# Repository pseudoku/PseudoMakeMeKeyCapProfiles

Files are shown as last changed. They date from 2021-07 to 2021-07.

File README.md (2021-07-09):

# Pseudo Make Me Key Cap Profile

## How to
* make sure OpenSCAD is up to date.
* unzip libraries.zip into your OpenSCAD libraries
* select keycap you want to render by changing KeyID value
* change KeyID to corresponding Parameter ID
* press F5 to review
* press F6 to render
* press F7 to export as STL

#Some notes on
## Distorted Ellipsoidal Saddle (DES)
High sculpt smooth transition profile
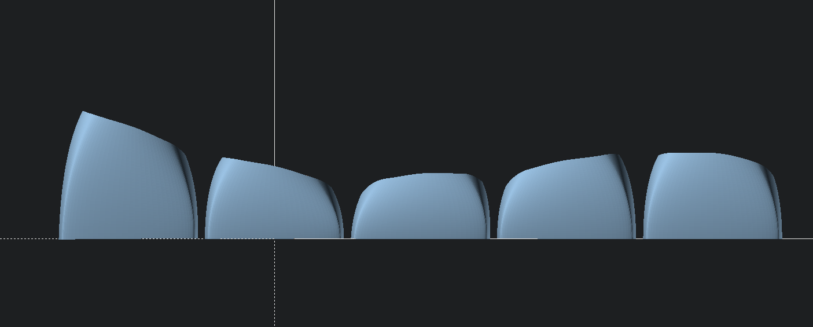
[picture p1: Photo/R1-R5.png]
DES

### Standard
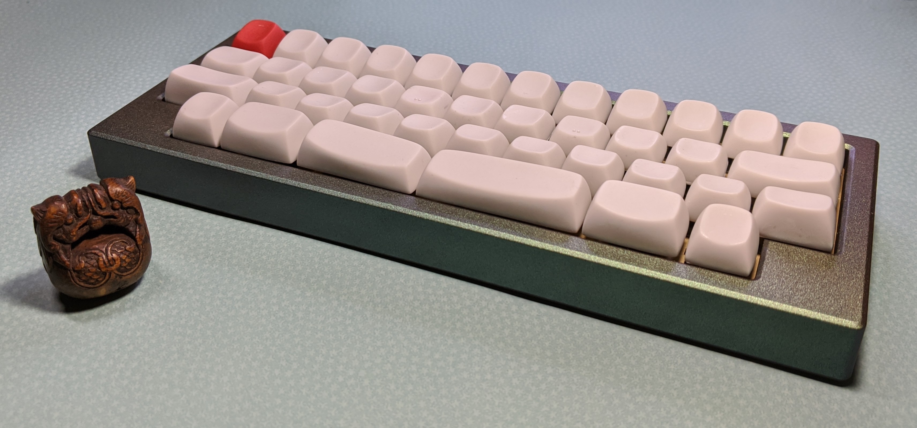
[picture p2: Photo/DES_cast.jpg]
Neuron v1


### Concave
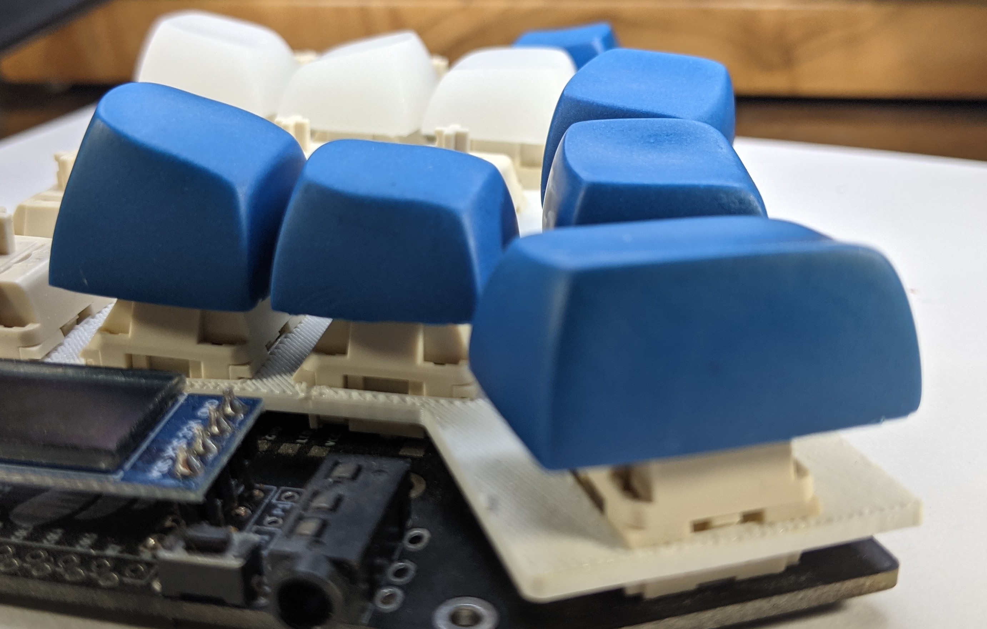
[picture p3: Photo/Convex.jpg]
Corne thumb and Convex Caps


### Thumbs
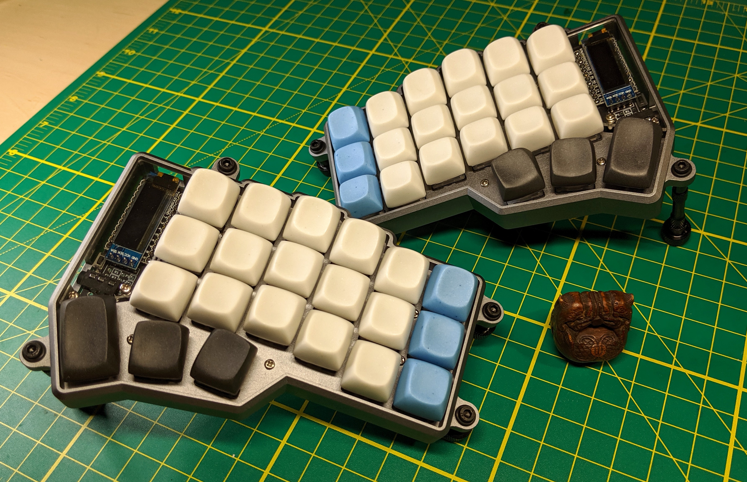
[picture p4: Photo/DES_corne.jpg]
IMK Corne v1

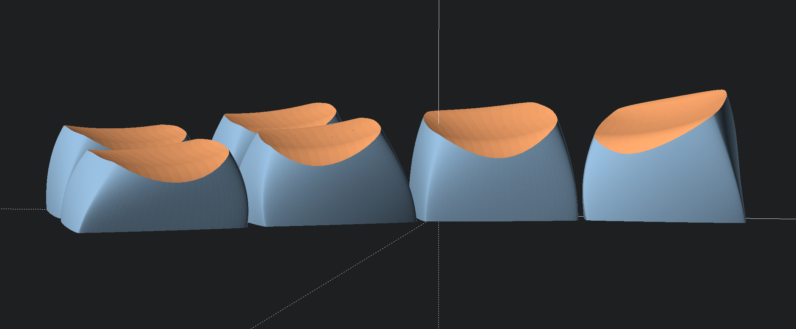
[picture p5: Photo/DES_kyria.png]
Kyria


### Chicago Stenographer
Subtly sculpted choc spaced low profile
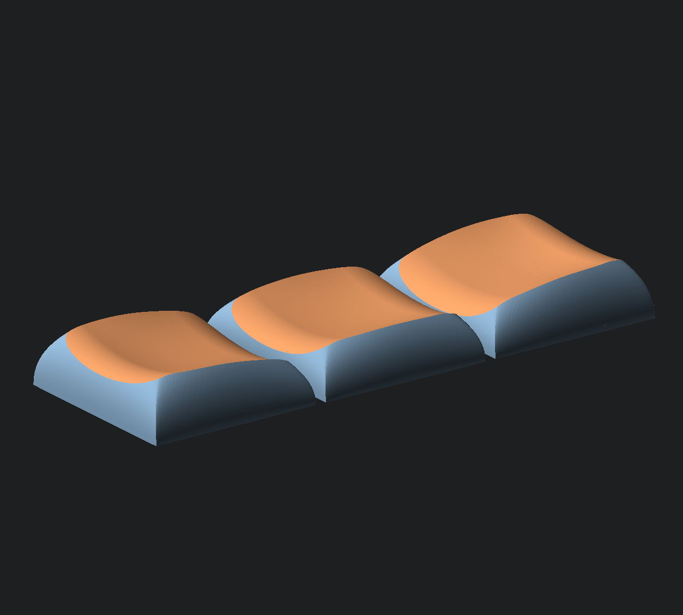
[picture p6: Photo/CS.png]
CS

#### Standard
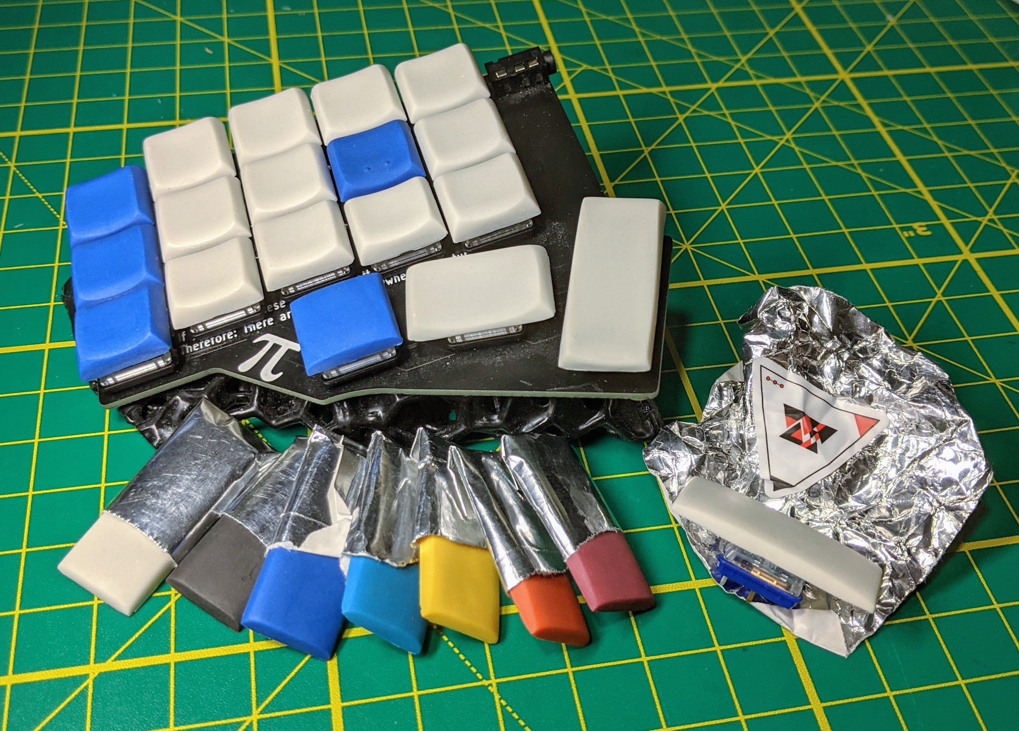
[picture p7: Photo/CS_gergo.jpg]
Look


#### Convex
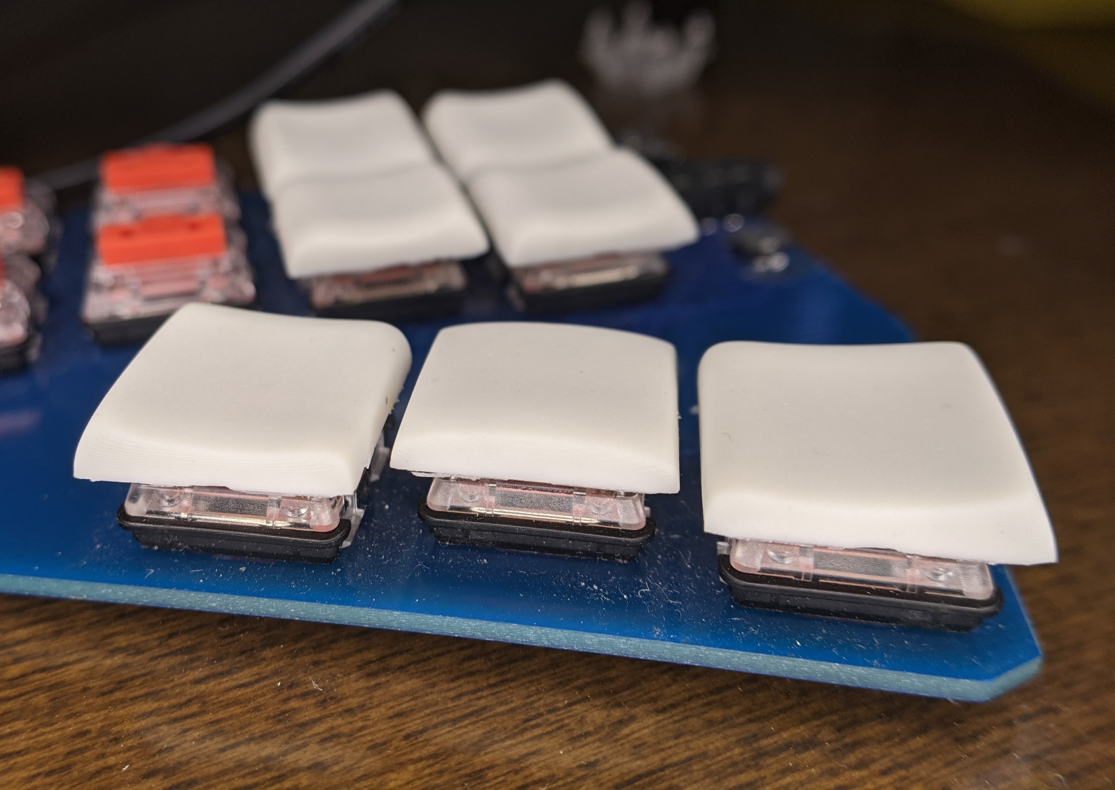
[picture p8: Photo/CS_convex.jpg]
Georgi

#### Thumbs
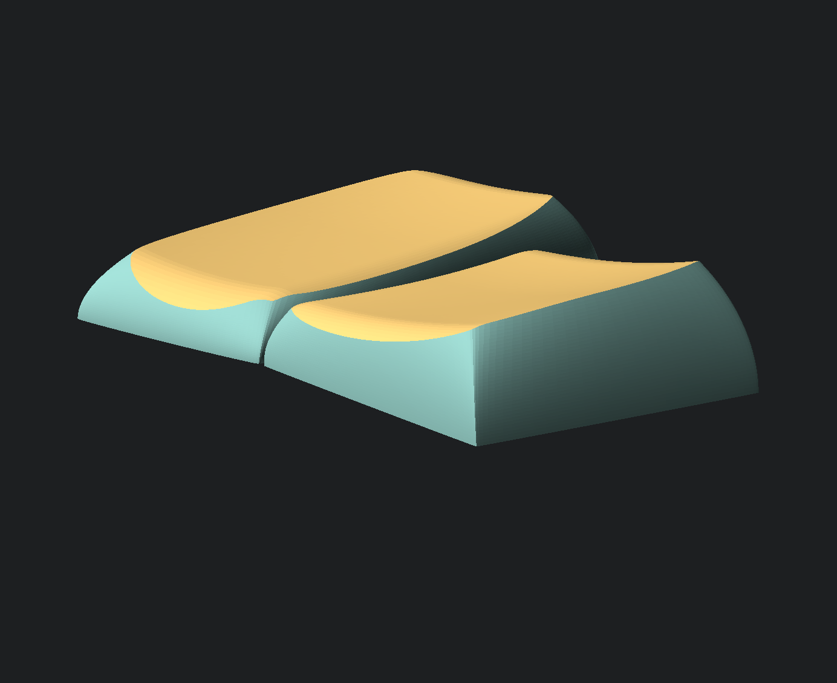
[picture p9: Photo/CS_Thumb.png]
1.5 + 1

Additional sculpt angle and smoother transitions

### Philadelphia Minimalist
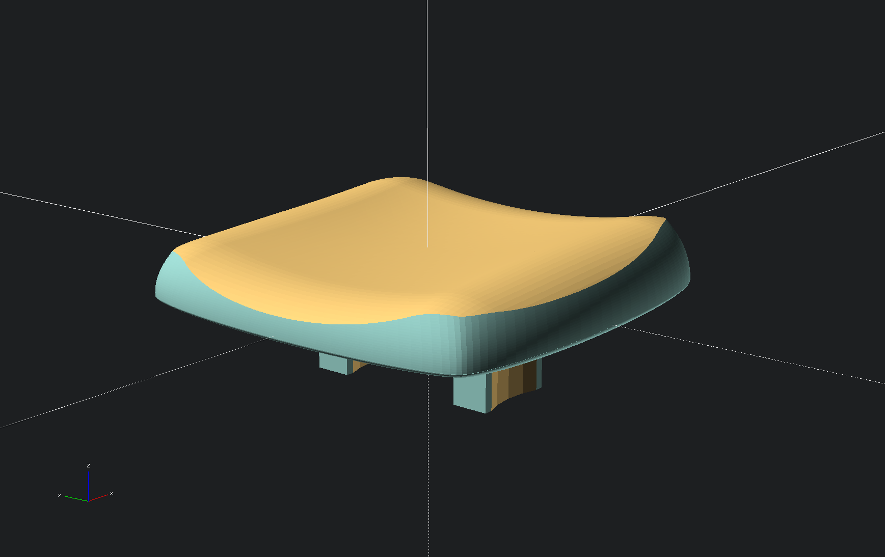
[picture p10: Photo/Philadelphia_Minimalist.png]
under

Minimal spacing
Under construction

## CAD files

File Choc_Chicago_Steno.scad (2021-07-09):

use <scad-utils/morphology.scad> //for cheaper minwoski 
use <scad-utils/transformations.scad>
use <scad-utils/shapes.scad>
use <scad-utils/trajectory.scad>
use <scad-utils/trajectory_path.scad>
use <sweep.scad>
use <skin.scad> 
//use <z-butt.scad> 

//Choc Chord version Chicago Stenographer

/*Tester */
keycap(
  keyID  = 1, //change profile refer to KeyParameters Struct
  cutLen = 0, //Don't change. for chopped caps
  Stem   = true, //tusn on shell and stems
  StemRot = 0, //change stem orientation by deg
  Dish   = true, //turn on dish cut
  Stab   = 0, 
  visualizeDish = false, // turn on debug visual of Dish 
  crossSection  = false, // center cut to check internal
  homeDot = false, //turn on homedots
  Legends = false
  ); 

//-Parameters
wallthickness = 1.1; // 1.75 for mx size, 1.1
topthickness = 2.5; //2 for phat 3 for chicago
stepsize = 50;  //resolution of Trajectory
step = 2;       //resolution of ellipes 
fn = 32;          //resolution of Rounded Rectangles: 60 for output
layers = 40;    //resolution of vertical Sweep: 50 for output

//---Stem param
slop    = 0.3;
stemRot = 0;
stemWid = 8;
stemLen = 6;
stemCrossHeight = 1.8;
extra_vertical = 0.6;
stemLayers = 50; //resolution of stem to cap top transition
//#cube([18.16, 18.16, 10], center = true); // sanity check border

//injection param
draftAngle = 0; //degree  note:Stem Only
//TODO: Add wall thickness transition?


keyParameters = //keyParameters[KeyID][ParameterID]
[
//  BotWid, BotLen, TWDif, TLDif, keyh, WSft, LSft  XSkew, YSkew, ZSkew, WEx, LEx, CapR0i, CapR0f, CapR1i, CapR1f, CapREx, StemEx
    //Column 0    
    //Levee: Chicago in choc Dimension 
    [17.20,  16.00,   5.6, 	   5,  4.9,    0,   .0,     5,    -0,    -0,   2, 2.5,    .10,      2,     .10,      3,     2,       2], //Chicago Steno R2/R4
    [17.20,  16.00,   5.6, 	   5,  4.5,    0,   .0,     0,    -0,    -0,   2, 2.5,    .10,      3,     .10,      3,     2,       2], //Chicago Steno R3 flat
    [17.20,  16.00,  1.25, 	1.25,  4.5,    0,   .0,     0,    -0,    -0,   2, 2.5,    .10,     .5,     .10,     .5,     2,       2], //Chicago Steno R3 chord
    //mods 3
    
    [17.20,  16.00,  4.25, 	3.25,  5.5,  -.7,  0.7,     0,    -4,    -0,   2,   2,    .10,      2,     .10,      2,     2,       2], //Levee Corner R2
    [17.20,  16.00,  4.25, 	3.25,  5.2,  -.8,  0.6,     0,    -4,    -0,   2,   3,    .10,      2,     .10,      2,     2,       2], //Levee Corner R2
    //1.25 5
    [21.3,   15.60,  5.6, 	   5,  4.5,    0,   .0,     5,    -0,    -0,   2,   2,     .5,      3,      .5,      3,     2,       2], //Chicago Steno R2/R4 1.25u
    [21.4,   15.60,  5.6, 	   5,  4.5,    0,   .0,     0,    -0,    -0,   2,   2,     .5,      3,      .5,      3,     2,       2], //Chicago Steno R3 1.25u
    //1.5 7
    [26.15,  15.60,   5.6, 	   5,  4.5,    0,   .0,     5,    -0,    -0,   2,   2,     .5,      3,      .5,      3,     2,       2], //Chicago Steno R2/R4 1.5
    [26.15,  15.60,   5.6, 	   5,  4.5,    0,   .0,     0,    -0,    -0,   2,   2,     .5,      3,      .5,      3,     2,       2], //Chicago Steno R3 1.5u
    //1.75 9
    [30.90,  15.60,   5.6, 	   5,  4.5,    0,   .0,     5,    -0,    -0,   2,   2,     .5,      3,      .5,      3,     2,       2], //Chicago Steno R2/R4 1.5
    [30.90,  15.60,   5.6, 	   5,  4.5,    0,   .0,     0,    -0,    -0,   2,   2,     .5,      3,      .5,      3,     2,       2], //Chicago Steno R3 1.5u
    //2.00 11
    [35.70,  15.60,   5.6, 	   5,  4.5,    0,   .0,     5,    -0,    -0,   2,   2,     .5,      3,      .5,      3,     2,       2], //Chicago Steno R2/R4 1.5
    [30.90,  15.60,   5.6, 	   5,  4.5,    0,   .0,     0,    -0,    -0,   2,   2,     .5,      3,      .5,      3,     2,       2], //Chicago Steno R3 1.5u
    // Ergo shits
    [18.75,  18.75,   5.6, 	   5,    8,    0,   .25,     0,    -0,    -0,   2, 2.5,    .10,      3,     .10,      3,     2,       2], //highpro 19.05 R2|4 
    [17.20,  16.00,   5.6, 	   5,  4.7,    0,   .0,      3,    -0,    -0,   2, 2.5,    .10,      2,     .10,      3,     2,       2], //Chicago Steno R2 ALT
    [17.20,  16.00,   5.6, 	   5,  5.5,    0,   .0,      7,    -0,    -0,   2, 2.5,    .10,      2,     .10,      3,     2,       2], //Chicago Steno R1 Steap
    [17.20,  16.00,   5.6, 	   5,  7.0,    0,   .0,     10,    -0,    -0,   2, 2.5,    .10,      2,     .10,      3,     2,       2] //Chicago Steno R1 mild with alt R2
];

dishParameters = //dishParameter[keyID][ParameterID]
[ 
//FFwd1 FFwd2 FPit1 FPit2  DshDep DshHDif FArcIn FArcFn FArcEx     BFwd1 BFwd2 BPit1 BPit2  BArcIn BArcFn BArcEx
  //Column 0
  [ 4.5,    4,    7,  -50,      7,    1.7,   11,    17,     2,      4.5,    4,    2,   -35,   11,    15,     2], //Chicago Steno R2/R4
  [ 4.5,    4,    5,  -40,      7,    1.7,   11,    15,     2,      4.5,    4,    5,   -40,   11,    15,     2], //Chicago Steno R3 flat
  [ 4.5,    4,    5,  -40,      7,    1.7,   11,    15,     2,      4.5,    4,    5,   -40,   11,    15,     2], //Chicago Steno R3 chord
  
  [   6,  3.5,    7,  -50,      5,    1.0,   16,    23,     2,        6,  3.5,    7,   -50,   16,    23,     2], //Levee Steno R2/R4
  [   6,  3.5,    7,  -50,      5,    1.0,   16,    23,     2,        6,  3.5,    7,   -50,   16,    23,     2], //Levee Steno R2/R4
  //1.25
  [ 4.5,    4,    7,  -40,      8,    1.8,   15,    20,     2,      4.5,    4,    2,   -35,   15,    20,     2], //Chicago Steno R2/R4
  [ 4.5,    4,    5,  -40,      8,    1.8,   15,    20,     2,      4.5,    4,    5,   -40,   15,    20,     2], //Chicago Steno R3
  //1.5
  [ 4.5,    4,    7,  -40,      8,    1.8,   19,    25,     2,      4.5,    4,    2,   -35,   19,    25,     2], //Chicago Steno R2/R4
  [ 4.5,    4,    5,  -40,      8,    1.8,   19,    25,     2,      4.5,    4,    5,   -40,   19,    25,     2], //Chicago Steno R3
  //1.75
  [ 4.5,    4,    7,  -40,      8,    1.8,   22.5,  27,     2,      4.5,    4,    2,   -35,   22.5,  27,     2], //Chicago Steno R2/R4
  [ 4.5,    4,    5,  -40,      8,    1.8,   22.5,  27,     2,      4.5,    4,    5,   -40,   22.5,  27,     2], //Chicago Steno R3
  //2.00
  [ 4.5,    4,    7,  -40,      8,    1.8,   22.5,  27,     2,      4.5,    4,    2,   -35,   22.5,  27,     2], //Chicago Steno R2/R4
  [ 4.5,    4,    5,  -40,      8,    1.8,   22.5,  27,     2,      4.5,    4,    5,   -40,   22.5,  27,     2], //Chicago Steno R3
  
  [   5,    5,    5,  -40,      7,    1.7,   11,    15,     2,        5,    5,    5,   -40,   11,    15,     2], //Chicago Steno R3 flat
  [ 4.5,    4,    7,  -50,      7,    1.7,   11,    17,     2,      4.5,    4,    2,   -35,   11,    15,     2], //Chicago Steno R1
  [ 4.5,    4,    7,  -50,      7,    1.7,   11,    17,     2,      4.5,    4,    2,   -35,   11,    15,     2], //Chicago Steno R1
  [ 4.5,    4,    7,  -50,      7,    1.7,   11,    17,     2,      4.5,    4,    2,   -35,   11,    15,     2] //Chicago Steno R1
];


function BottomWidth(keyID)  = keyParameters[keyID][0];  //
function BottomLength(keyID) = keyParameters[keyID][1];  // 
function TopWidthDiff(keyID) = keyParameters[keyID][2];  //
function TopLenDiff(keyID)   = keyParameters[keyID][3];  //
function KeyHeight(keyID)    = keyParameters[keyID][4];  //
function TopWidShift(keyID)  = keyParameters[keyID][5];
function TopLenShift(keyID)  = keyParameters[keyID][6];
function XAngleSkew(keyID)   = keyParameters[keyID][7];
function YAngleSkew(keyID)   = keyParameters[keyID][8];
function ZAngleSkew(keyID)   = keyParameters[keyID][9];
function WidExponent(keyID)  = keyParameters[keyID][10];
function LenExponent(keyID)  = keyParameters[keyID][11];
function CapRound0i(keyID)   = keyParameters[keyID][12];
function CapRound0f(keyID)   = keyParameters[keyID][13];
function CapRound1i(keyID)   = keyParameters[keyID][14];
function CapRound1f(keyID)   = keyParameters[keyID][15];
function ChamExponent(keyID) = keyParameters[keyID][16];
function StemExponent(keyID) = keyParameters[keyID][17];

function FrontForward1(keyID) = dishParameters[keyID][0];  //
function FrontForward2(keyID) = dishParameters[keyID][1];  // 
function FrontPitch1(keyID)   = dishParameters[keyID][2];  //
function FrontPitch2(keyID)   = dishParameters[keyID][3];  //
function DishDepth(keyID)     = dishParameters[keyID][4];  //
function DishHeightDif(keyID) = dishParameters[keyID][5];  //
function FrontInitArc(keyID)  = dishParameters[keyID][6];
function FrontFinArc(keyID)   = dishParameters[keyID][7];
function FrontArcExpo(keyID)  = dishParameters[keyID][8];
function BackForward1(keyID)  = dishParameters[keyID][9];  //
function BackForward2(keyID)  = dishParameters[keyID][10];  // 
function BackPitch1(keyID)    = dishParameters[keyID][11];  //
function BackPitch2(keyID)    = dishParameters[keyID][12];  //
function BackInitArc(keyID)   = dishParameters[keyID][13];
function BackFinArc(keyID)    = dishParameters[keyID][14];
function BackArcExpo(keyID)   = dishParameters[keyID][15];
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

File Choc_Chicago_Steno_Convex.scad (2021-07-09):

use <scad-utils/morphology.scad> //for cheaper minwoski 
use <scad-utils/transformations.scad>
use <scad-utils/shapes.scad>
use <scad-utils/trajectory.scad>
use <scad-utils/trajectory_path.scad>
use <sweep.scad>
use <skin.scad>  
//use <z-butt.scad>

//NOTE: with sweep cuts, top surface may not be visible in review, it should be visible once rendered

mirror([0,0,0])keycap(
  keyID  = 1, //change profile refer to KeyParameters Struct
  cutLen = 0, //Don't change. for chopped caps
  Stem   = true, //tusn on shell and stems
  StemRot = 0,//change stem orientation by deg
  Dish   = true, //turn on dish cut
  Stab   = 0, 
  visualizeDish = false, // turn on debug visual of Dish 
  crossSection  = false, // center cut to check internal
  homeDot = false, //turn on homedots
  Legends = false
); 

//Parameters
wallthickness = 1.2;   
topthickness  = 2;   //
stepsize      = 50;  //resolution of Trajectory
step          = 1;   //resolution of ellipes 
fn            = 32;  //resolution of Rounded Rectangles: 60 for output
layers        = 40;  //resolution of vertical Sweep: 50 for output
dotRadius     = 1.25;   //home dot size
//---Stem param
slop    = 0.25;
stemWid = 8;
stemLen = 6;
stemCrossHeight = 1.8;
extra_vertical  = 0.6;
StemBrimDep     = 0; 
stemLayers      = 50; //resolution of stem to cap top transition
driftAngle      = 0;

keyParameters = //keyParameters[KeyID][ParameterID]
[
//  BotWid, BotLen, TWDif, TLDif, keyh, WSft, LSft  XSkew, YSkew, ZSkew, WEx, LEx, CapR0i, CapR0f, CapR1i, CapR1f, CapREx, StemEx
    //Column 0    
    //Levee: Chicago in choc Dimension 
    [17.20,  16.00,   5.6, 	   5,  3.8,    0,  -.5,     7,    -0,    -0,   2, 2,    .10,      3,     .10,      3,     2,       2], //Chicago Steno R2x 1u
    [17.20,  16.00,   5.6, 	   5,  4.4,    0,   .0,     0,    -0,    -0,   2, 2,    .10,      3,     .10,      3,     2,       2], //Chicago Steno R3x 1u
    [35.85,  15.65,     7, 	   7,  4.4,    0,   .0,     0,    -0,    -0,   2, 2,    .30,      5,     .30,      5,     2,       2], //Chicago Steno R3x 1.5u 
    [35.85,  15.65,     7, 	   7,  4.4,    0,   .0,     0,    -0,    -0,   2, 2,    .30,      5,     .30,      5,     2,       2], //Chicago Steno R3x 2u 
    //mods 3
    
    [17.20,  16.00,  4.25, 	3.25,  5.5,  -.7,  0.7,     0,    -4,    -0,   2,   2,    .10,      2,     .10,      2,     2,       2], //Levee Corner R2
    [17.20,  16.00,  4.25, 	3.25,  5.2,  -.8,  0.6,     0,    -4,    -0,   2,   3,    .10,      2,     .10,      2,     2,       2], //Levee Corner R2
    //1.25 5
    [21.3,   15.60,  5.6, 	   5,  4.5,    0,   .0,     5,    -0,    -0,   2,   2,     .5,      3,      .5,      3,     2,       2], //Chicago Steno R2/R4 1.25u
    [21.4,   15.60,  5.6, 	   5,  4.5,    0,   .0,     0,    -0,    -0,   2,   2,     .5,      3,      .5,      3,     2,       2], //Chicago Steno R3 1.25u
    //1.5 7
    [26.15,  15.60,   5.6, 	   5,  4.5,    0,   .0,     5,    -0,    -0,   2,   2,     .5,      3,      .5,      3,     2,       2], //Chicago Steno R2/R4 1.5
    [26.15,  15.60,   5.6, 	   5,  4.5,    0,   .0,     0,    -0,    -0,   2,   2,     .5,      3,      .5,      3,     2,       2], //Chicago Steno R3 1.5u
    //1.75 9
    [30.90,  15.60,   5.6, 	   5,  4.5,    0,   .0,     5,    -0,    -0,   2,   2,     .5,      3,      .5,      3,     2,       2], //Chicago Steno R2/R4 1.5
    [30.90,  15.60,   5.6, 	   5,  4.5,    0,   .0,     0,    -0,    -0,   2,   2,     .5,      3,      .5,      3,     2,       2], //Chicago Steno R3 1.5u
    // Ergo shits
    [18.75,  18.75,   5.6, 	   5,    8,    0,   .25,     0,    -0,    -0,   2, 2.5,    .10,      3,     .10,      3,     2,       2], //highpro 19.05 R2|4 
    [17.20,  16.00,   5.6, 	   5,  4.7,    0,   .0,      3,    -0,    -0,   2, 2.5,    .10,      2,     .10,      3,     2,       2], //Chicago Steno R2 ALT
    [17.20,  16.00,   5.6, 	   5,  5.5,    0,   .0,      7,    -0,    -0,   2, 2.5,    .10,      2,     .10,      3,     2,       2], //Chicago Steno R1 Steap
    [17.20,  16.00,   5.6, 	   5,  7.0,    0,   .0,     10,    -0,    -0,   2, 2.5,    .10,      2,     .10,      3,     2,       2], //Chicago Steno R1 mild with alt R2
];

dishParameters = //dishParameter[keyID][ParameterID]
[ 
//FFwd1 FFwd2 FPit1 FPit2  DshDepi DishDepf,DshHDif FArcIn FArcFn FArcEx     BFwd1 BFwd2 BPit1 BPit2  BArcIn BArcFn BArcEx
  [   5,  2.3,    2,  -55,    1.5,   3.75,   8.5,    8.5,    2,       5,    3,    2,  -50,    8.5,    8.7 ,     2], //R2x 1u
  [ 4.5,  3.3,   -3,  -45,    1.5,   3.75,   8.5,   8.7,     2,     4.5,  3.3,   -3,  -45,    8.5,   8.7,     2], //R3x 1u
  [ 4.5,  3.2,   -5,  -45,    1.5,   3.75,  19.0,    18,     2,     4.5,  3.2,   -5,  -45,   19.0,    18,     2], //R3x 2u
  [ 4.5,  3.2,   -5,  -45,    1.5,   3.75,  19.0,    18,     2,     4.5,  3.2,   -5,  -45,   19.0,    18,     2], //R3x 2u
  [   4,  4.2,   -5,  -15,      1,      3,  18.2,    21,     2,       5,    3,   -5,  -15,   18.2,    21,     2], //R3 2u
  [  4.,  1.5,    8,  -55,      3,      7,   9.0,     9,     2,       4,    3,    3,  -50,    9,     9,     2],  //R3
  [  4.,  1.5,   -0,  -50,      3,      7,   9.0,     9,     2,       4,    3,    -10,  -50,    9,     9,     2],  //R3
  [   5,  3.5,    8,  -50,      5,    1.8,   8.8,    15,     2,       6,    4,   13,   30,    8.8,    16,     2], //R1
];
 
function FrontForward1(keyID) = dishParameters[keyID][0];  //
function FrontForward2(keyID) = dishParameters[keyID][1];  // 
function FrontPitch1(keyID)   = dishParameters[keyID][2];  //
function FrontPitch2(keyID)   = dishParameters[keyID][3];  //
function DishDepth(keyID)     = dishParameters[keyID][4];  //
function DishHeightDif(keyID) = dishParameters[keyID][5];  //
function FrontInitArc(keyID)  = dishParameters[keyID][6];
function FrontFinArc(keyID)   = dishParameters[keyID][7];
function FrontArcExpo(keyID)  = dishParameters[keyID][8];
function BackForward1(keyID)  = dishParameters[keyID][9];  //
function BackForward2(keyID)  = dishParameters[keyID][10];  // 
function BackPitch1(keyID)    = dishParameters[keyID][11];  //
function BackPitch2(keyID)    = dishParameters[keyID][12];  //
function BackInitArc(keyID)   = dishParameters[keyID][13];
function BackFinArc(keyID)    = dishParameters[keyID][14];
function BackArcExpo(keyID)   = dishParameters[keyID][15];

function BottomWidth(keyID)  = keyParameters[keyID][0];  //
function BottomLength(keyID) = keyParameters[keyID][1];  // 
function TopWidthDiff(keyID) = keyParameters[keyID][2];  //
function TopLenDiff(keyID)   = keyParameters[keyID][3];  //
function KeyHeight(keyID)    = keyParameters[keyID][4];  //
function TopWidShift(keyID)  = keyParameters[keyID][5];
function TopLenShift(keyID)  = keyParameters[keyID][6];
function XAngleSkew(keyID)   = keyParameters[keyID][7];
function YAngleSkew(keyID)   = keyParameters[keyID][8];
function ZAngleSkew(keyID)   = keyParameters[keyID][9];
function WidExponent(keyID)  = keyParameters[keyID][10];
function LenExponent(keyID)  = keyParameters[keyID][11];
function CapRound0i(keyID)   = keyParameters[keyID][12];
function CapRound0f(keyID)   = keyParameters[keyID][13];
function CapRound1i(keyID)   = keyParameters[keyID][14];
function CapRound1f(keyID)   = keyParameters[keyID][15];
function ChamExponent(keyID) = keyParameters[keyID][16];
function StemExponent(keyID) = keyParameters[keyID][17];

function FrontTrajectory(keyID) = 
  [
    trajectory(forward = FrontForward1(keyID), pitch =  FrontPitch1(keyID)), //more param available: yaw, roll, scale
    trajectory(forward = FrontForward2(keyID), pitch =  FrontPitch2(keyID))  //You can add more traj if you wish 
  ];

function BackTrajectory (keyID) = 
  [
    trajectory(forward = BackForward1(keyID), pitch =  BackPitch1(keyID)),
    trajectory(forward = BackForward2(keyID), pitch =  BackPitch2(keyID)),
  ];

//------- function defining Dish Shapes

function ellipse(a, b, d = 0, rot1 = 0, rot2 = 360) = [for (t = [rot1:step:rot2]) [a*cos(t)+a, b*sin(t)*(1+d*cos(t))]]; //Centered at a apex to avoid inverted face

function DishShape (a,b,c,d) = 
  concat(
   [[c+a,-b]],
    ellipse(a, b, d = 0,rot1 = 270, rot2 =450),
   [[c+a,b]]
  );

function oval_path(theta, phi, a, b, c, deform = 0) = [
 a*cos(theta)*cos(phi), //x
 c*sin(theta)*(1+deform*cos(theta)) , // 
 b*sin(phi),
]; 
  
path_trans2 = [for (t=[0:step:180])   translation(oval_path(t,0,10,15,2,0))*rotation([0,90,0])];


//--------------Function definng Cap 
function CapTranslation(t, keyID) = 
  [
    ((1-t)/layers*TopWidShift(keyID)),   //X shift
    ((1-t)/layers*TopLenShift(keyID)),   //Y shift
    (t/layers*KeyHeight(keyID))    //Z shift
  ];

function InnerTranslation(t, keyID) =
  [
    ((1-t)/layers*TopWidShift(keyID)),   //X shift
    ((1-t)/layers*TopLenShift(keyID)),   //Y shift
    (t/layers*(KeyHeight(keyID)-topthickness))    //Z shift
  ];
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

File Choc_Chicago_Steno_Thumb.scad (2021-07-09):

use <scad-utils/morphology.scad> //for cheaper minwoski 
use <scad-utils/transformations.scad>
use <scad-utils/shapes.scad>
use <scad-utils/trajectory.scad>
use <scad-utils/trajectory_path.scad>
use <sweep.scad>
use <skin.scad>  
//use <z-butt.scad>
// Choc Chord version Chicago Stenographer with sculpte Thumb cluter
// change stemrot 

mirror([1,0,0])keycap(
  keyID   = 1, //change profile refer to KeyParameters Struct
  cutLen  = 0, //Don't change. for chopped caps
  Stem    = true, //tusn on shell and stems
  StemRot = 0,//change stem orientation by deg
  Dish    = true, //turn on dish cut
  Stab    = 0, 
  visualizeDish = false, // turn on debug visual of Dish 
  crossSection  = false, // center cut to check internal
  homeDot = false, //turn on homedots
  Legends = false
); 

//-Parameters
wallthickness = 1.1; // 1.75 for mx size, 1.1
topthickness = 2.5; //2 for phat 3 for chicago
stepsize = 40;  //resolution of Trajectory
step =2;       //resolution of ellipes 
fn = 32;          //resolution of Rounded Rectangles: 60 for output
layers = 40;    //resolution of vertical Sweep: 50 for output

//---Stem param
slop    = 0.3;
stemWid = 8;
stemLen = 6;
stemCrossHeight = 1.8;
extra_vertical = 0.6;
stemLayers = 50; //resolution of stem to cap top transition
//#cube([18.16, 18.16, 10], center = true); // sanity check border

//injection param
draftAngle = 0; //degree  note:Stem Only
//TODO: Add wall thickness transition?

keyParameters = //keyParameters[KeyID][ParameterID]
[
//  BotWid, BotLen, TWDif, TLDif, keyh, WSft, LSft  XSkew, YSkew, ZSkew, WEx, LEx, CapR0i, CapR0f, CapR1i, CapR1f, CapREx, StemEx
    //Column 0    
    //Levee: Chicago in choc Dimension for ref 
    [17.20,  16.00,   5.6, 	   5,  5.0,    0,   .0,     5,    -0,    -0,   2, 2.5,    .10,      2,     .10,      3,     2,       2], //Levee Steno R2/R4 
    [17.20,  16.00,   5.6, 	   5,  4.6,    0,   .0,     0,    -0,    -0,   2, 2.5,    .10,      3,     .10,      3,     2,       2], //Levee Steno R3
    //Thumb
    [17.20,  16.00,  4.25, 	3.25,  5.0,  -.5,  0.0,    -3,    -3,    -0,   2,   2,    .10,      2,     .10,      2,     2,       2], //Thumb 1
    [15.65,  26.4,   5.5, 	3.25,  4.9,  -.5,  0.0,    -3,    -2,    -2,   2,   2,     .3,      2,      .3,    2.5,     2,       2], //Thumb 1.5
    [15.65,  35.8,  4.25, 	3.25,  4.9, -.25,  0.0,    -2.5,    -4,    -2,   2,   3,     .3,      2,      .3,    2.5,     2,       2], //Thumb 2.0
    //1.25 5
    [21.3,   15.60,  5.6, 	   5,  4.5,    0,   .0,     5,    -0,    -0,   2,   2,     .5,      3,      .5,      3,     2,       2], //Chicago Steno R2/R4 1.25u
    [21.4,   15.60,  5.6, 	   5,  4.5,    0,   .0,     0,    -0,    -0,   2,   2,     .5,      3,      .5,      3,     2,       2], //Chicago Steno R3 1.25u
    //1.5 7
    [26.15,  15.60,   5.6, 	   5,  4.5,    0,   .0,     5,    -0,    -0,   2,   2,     .5,      3,      .5,      3,     2,       2], //Chicago Steno R2/R4 1.5
    [26.15,  15.60,   5.6, 	   5,  4.5,    0,   .0,     0,    -0,    -0,   2,   2,     .5,      3,      .5,      3,     2,       2], //Chicago Steno R3 1.5u
    //1.75 9
    [30.90,  15.60,   5.6, 	   5,  4.5,    0,   .0,     5,    -0,    -0,   2,   2,     .5,      3,      .5,      3,     2,       2], //Chicago Steno R2/R4 1.5
    [30.90,  15.60,   5.6, 	   5,  4.5,    0,   .0,     0,    -0,    -0,   2,   2,     .5,      3,      .5,      3,     2,       2], //Chicago Steno R3 1.5u
    // Ergo shits
    [18.75,  18.75,   5.6, 	   5,    8,    0,   .25,     0,    -0,    -0,   2, 2.5,    .10,      3,     .10,      3,     2,       2], //highpro 19.05 R2|4 
    [17.20,  16.00,   5.6, 	   5,  4.7,    0,   .0,      3,    -0,    -0,   2, 2.5,    .10,      2,     .10,      3,     2,       2], //Chicago Steno R2 ALT
    [17.20,  16.00,   5.6, 	   5,  5.5,    0,   .0,      7,    -0,    -0,   2, 2.5,    .10,      2,     .10,      3,     2,       2], //Chicago Steno R1 Steap
    [17.20,  16.00,   5.6, 	   5,  7.0,    0,   .0,     10,    -0,    -0,   2, 2.5,    .10,      2,     .10,      3,     2,       2], //Chicago Steno R1 mild with alt R2

];
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

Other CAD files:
DES_Choc_Levee.scad
DES_ChocChordCaps.scad
DES_Cornes.scad
DES_Levee.scad
DES_MX_3row_heavy sculpt.scad
DES_MX_Concave.scad
DES_MX_Manuform.scad
DES_superflat.scad
MX_DES_Convex.scad
MX_DES_Standard.scad
MX_DES_Thumb.scad
Philadelphia_Minimalist.scad

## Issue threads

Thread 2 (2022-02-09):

Printing in MJF nylon

toniz4, 2022-02-09:
Hello, first of all that's a really nice project.

Since jlcpcb started receiving 3d printing orders, I wanted to get a set of keycaps printed by them in MJF nylon. Anyone has tried that with success? Or will I be the guinea pig?

deanraspa, 2022-06-05:
@toniz4, did you end up getting them printed?  I am in the same boat.

caksoylar, 2022-06-05:
I got the DES keycaps printed in MJF with JLCPCB. They asked a few questions about weak spots and I accepted the risk. The keycaps turned out fine: The stem holes for about half of the keycaps were a bit loose so it wobbles on my switches, but I worked around it by putting some scotch tape on the stems before inserting the keycaps and it tightened things up enough.

toniz4, 2022-06-27:
@caksoylar Did you changed the Tol parameter? By default it adds some tolerance to the stem holes, did you had setted to 0?

caksoylar, 2022-07-02:
@toniz4 I used the default settings in the thumb and convex scads, but used the STLs Pseudoku posted themselves at their Discord channel. I haven't compared those STLs to those generated from the scad file directly to say whether they are different or not.

Here is a direct link to the STLs on the Discord channel: https://discord.com/channels/714176584269168732/879817722328920174/953708184848179240
Here is an invite to the server if you need it: https://discord.gg/DbCfZfZ

toniz4, 2022-07-28:
I 3d printed those in mjf, in general it fits really thigh with `Tol = 0`. Here are the details:

https://www.reddit.com/r/ErgoMechKeyboards/comments/waj7zw/mjf_3d_printed_pseudoku_keycaps/

Closed 2022-07-28.

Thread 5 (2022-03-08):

Help on how to 3d print these

uqs, 2022-03-08:
Hi there, I'm trying to get these printed on an FDM printer with a 0.4mm nozzle, but I'm running into various issues.

Because the stem is slightly offset (why?) I'd need to turn on supports, but these then are hard to remove again and they are not needed for the bridging on the top anyway (and I haven't found a way to stop all supports at a certain z-height (yet).

Printing them upside-down avoids that issue, but then the top-side comes out ugly (with supports).

The stem is pretty thin/fragile anyway with such a setup, do you recommend a resin printer for these?

I've also tried extending the stem down to the build plate, but this also doesn't work without supports, as it starts with the 4 tiny corners and they don't hold on to the build plate.

The last issue can probably be fixed by adding 4 spans at z=0 that connect the stem corners to the side of the cap and can be snipped at way after the print is done. wdyt?

julowe, 2022-03-29:
I've had good results printing the Chicago Steno keycaps vertically, with supports only for the stems. Just let the wall/underside of the keycap (which would be facing away from you when the keycap is on a keyboard) be a bridge and sag a little, it's unseen and at least on my printer (Ender 3, no real upgrades, 0.4mm nozzle), doesn't sag anywhere near enough to hit the keyswitch body when pressed down. And because pictures are easier than lots of words, see attached pictures below from my slicing program (prusaSlicer) to see what I mean. If you're unfamiliar with Slicer, the small transparent boxes are the support enforcers and supports are only generated for those parts. Also, printing them like this make the sliced layers perpendicular to the stem-keycap attachment point and thus stronger/less likely to snap off at that point.

Someone else somewhere said they have had success printing keycaps at a slight angle. I haven't done it, but for reference I attached a screenshot of the keycap angled 30 degrees like they said they did. Seems like it woudl work fine to me, have printed other fiddly objects (28mm mini figs) like this at angles and they printed well and were sturdy. This orientation might be better  if you are printing taller keycaps (vs the choc chicago steno) and play with angles or some more selective supports (back keycap wall?)

Unsliced vertical orientation
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

Sliced Vertical
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

30 Degree rotation sliced
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

Emburglar, 2022-08-23:
Do you have stls to this? Im having a hard time with openscad.....:/

julowe, 2022-08-24:
Not sure who you are replying to/which keycaps you want - probably the DES MX caps immediately preceding - but just in case it's the steno chocs I have some STLs in my [dev mess branch of the forked repo](https://github.com/julowe/PseudoMakeMeKeyCapProfiles/tree/dev-mess/STL) I think that is all the rows for... well I was going to say **a** keyboard, but maybe just for my gergoplex. Let me know if there are STLs/rows missing

seltzered, 2022-09-25:
@uqs _"For choc stems you need to get more creative indeed."_ thanks for mentioning this. I'm thinking of building my first keyboard with choc switches ( https://www.reddit.com/r/ErgoMechKeyboards/comments/x6mbjh/seeking_design_feedback_atreusinspired_extended/ ) inspired by the 'philadelphia minimalist' caps and starting think it makes more sense to either make resin caps ( https://kbd.news/Homemade-keycaps-1643.html goes into this ) or possibly do some hybrid of adding moulding on top of chopped keycaps.

MrMarble, 2024-09-17:
@Emburglar a bit late, but you have some stls here https://www.printables.com/model/865075-des-keycaps-for-keyboard-cherry-mx-version/files

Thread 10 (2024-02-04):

Cross is too loose

juniorsaldanha, 2024-02-04:
Hi, hive generated the files and printed using resin printer (Elegoo), but my the cross of the keyscaps its losse, it doesnt hold on the switch.

I'm not not a export of scad files and how to customize it, so if any one could help me making the cross tighter it would be really nice.

I've tried to debug the scad file/code but its just some really new and different for me.

:)

juniorsaldanha, 2024-02-04:
I've found how to do it.

`Tol=0.1` to `Tol=0` variable on line 36, i'll print again and give some feedback.

I think we should some how rewrite this code to be more friendly, and add a pipeline to Build it.

caksoylar, 2024-02-04:
If you haven't yet, it might be worth checking some of the forks like https://github.com/sporkus/PseudoMakeMeKeyCapProfiles that have STLs, makefiles for building, etc.

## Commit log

2019-07-19 init
    initial commit
    [KeyCap.scad]
2019-08-05 Init
    Init to pub
    [C0R2.stl, C0R3.stl, C0R4.stl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]
2019-08-05 removed STL
2019-08-06 fixed inversion condition
    Adjusted height param on thumb cluster to avoid inversion from stemtransform
    [DES_ChocChordCaps.scad, DES_Cornes.scad]
2019-08-06 removed trashes
    [ChocKeyCap.scad, ChocKeyCap.stl, ChocT1.stl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]
2019-08-06 Stem Draft Angle
    * Added Stem Draft Angle to be adjusted for injection molding.
    * Adjusted approach exponents to avoid concavity for injection molding
    * Added Uniform Phat
    [DES_ChocChordCaps.scad, DES_Cornes.scad]
2019-08-07 Fixed bug on roundness function
    wrong peranthesis location causing wrong initial axis length.
    [DES_ChocChordCaps.scad, DES_Cornes.scad, RP_MX.scad]
2019-08-14 RP and DES update
    Added choc 1.5 mods
    updated RP dish
    minor adjustment on DES corne
    [DES_ChocChordCaps.scad, DES_Cornes.scad, RP_MX.scad]
2019-09-05 Levee and Kyria
    Added thumb cluster for kyria on DES_Corne. Added choc dimension version Chicago Steno: Levee and Phat with corner dishing.
    [DES_Levee.scad, DES_MiniWarp.scad, RP_Choc.scad]
2019-09-07 Adjustment On Levee
    Size correction and tuned secondary dish depth.
    [DES_Levee.scad]
2019-09-18 file renaming and concaves
    [DES_Choc_ChicagoSteno.scad, DES_Choc_Concave.scad, DES_Choc_Levee.scad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]
2019-09-25 Knob and Lib
    added encoder knob and some instructions for end user.
    [DES_Choc_ChicagoSteno.scad, DES_Choc_Levee.scad, DES_MX_Corne+Kyria.scad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]
2019-10-08 RP update and Injection Mold Output
    updated RP
    Injection mold for DES intial trial
    [DES_IJM.scad, RP_MX.scad]
2019-12-15 zbutt and profile updates
    updated profiles
    also mold generators for zbutt
    [DES_Choc_ChicagoSteno.scad, DES_Choc_Concave.scad, DES_Choc_Levee.scad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]
2021-07-09 Oh my, I'm actually updating.
    Cleaned clutters, updated photos for once, Still utter spaghetti.
    [Choc_Chicago_Steno.scad, Choc_Chicago_Steno_Convex.scad, Choc_Chicago_Steno_Thumb.scad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]
